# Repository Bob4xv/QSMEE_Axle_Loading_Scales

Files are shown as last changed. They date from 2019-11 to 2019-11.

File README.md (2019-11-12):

This project was created for the Queensland Society of Model and Experimental Engineers (QSMEE) 
to provide a facility to measure the load presented by a locomotive axles individually.  This
enables the builders of their scale model locomotives to equalize each axle as required on both 
5" and 7 1/4" gauge track.
A facility was added to add each axle to memory giving a total weight of the locomotive.

Hardware requirements:-
Arduino uno processor, HX711 SPI Loadcell ADC, 8 character 7 segment LED I2C display module.
The load cells are two LC4103-K100 in parallel supporting a track segment.

Software requirements:-
Arduino IDE with the following libraries installed. 
	LedControl-master from git-hub.  https://github.com/wayoda/LedControl
	HX711_ADC-master from git-hub. https://github.com/olkal/HX711_ADC & https://github.com/bogde/HX711

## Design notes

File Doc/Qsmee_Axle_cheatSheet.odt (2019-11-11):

QSMEE Axle load Scales

User Guide

POWER ON :

Push the Power switch down and hold until the display lights up with “8888” then

release. This will power the scales up for approx 30 minutes and then power it self

down.

Zero Reading:

Pressing this button down while there is no weight on the measuring part of the track

will set the tare weight to zero. Use this switch when ever the weight display does

not read 0.0 on the right hand end of the display when there is no load on the scales.

Mem +

Pressing the right hand Mem + switch down will cause the current weight displayed

on the right hand end of the display to be added to the MEMORY part of the display

on the left hand side.

Mem Clr

Pressing the right hand Mem Clr button up will reset the value in MEMORY back to

zero.

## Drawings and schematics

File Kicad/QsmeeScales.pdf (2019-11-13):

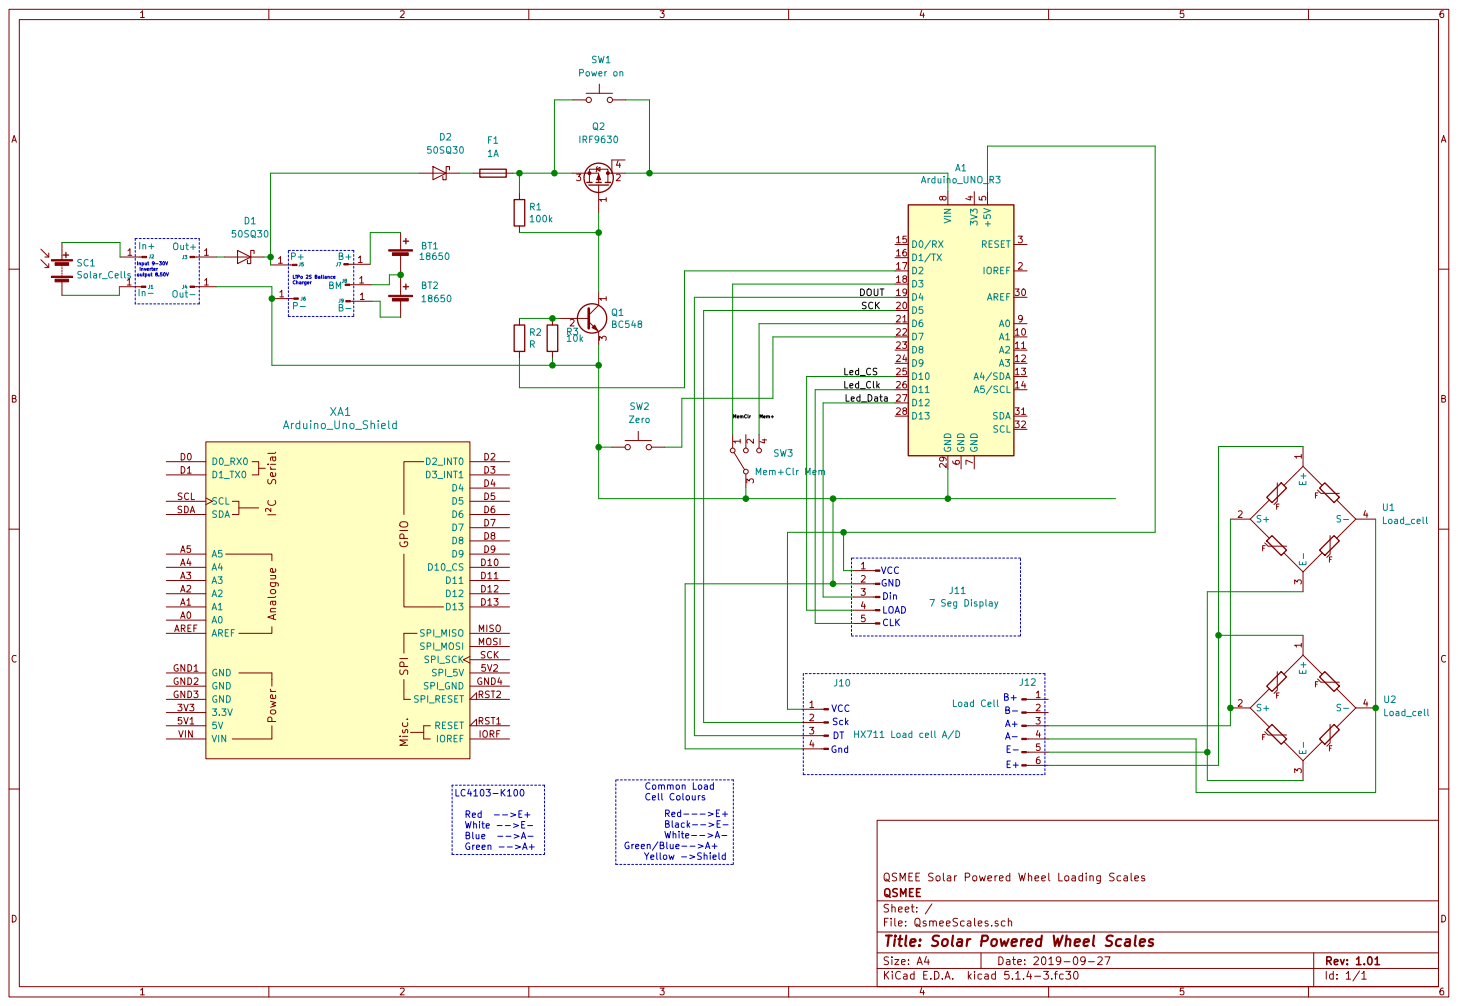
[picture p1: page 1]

QSMEE Solar Powered Wheel Loading Scales 12345

File: QsmeeScales.sch Sheet: / QSMEE

Id: 1/1 Title: Solar Powered Wheel Scales

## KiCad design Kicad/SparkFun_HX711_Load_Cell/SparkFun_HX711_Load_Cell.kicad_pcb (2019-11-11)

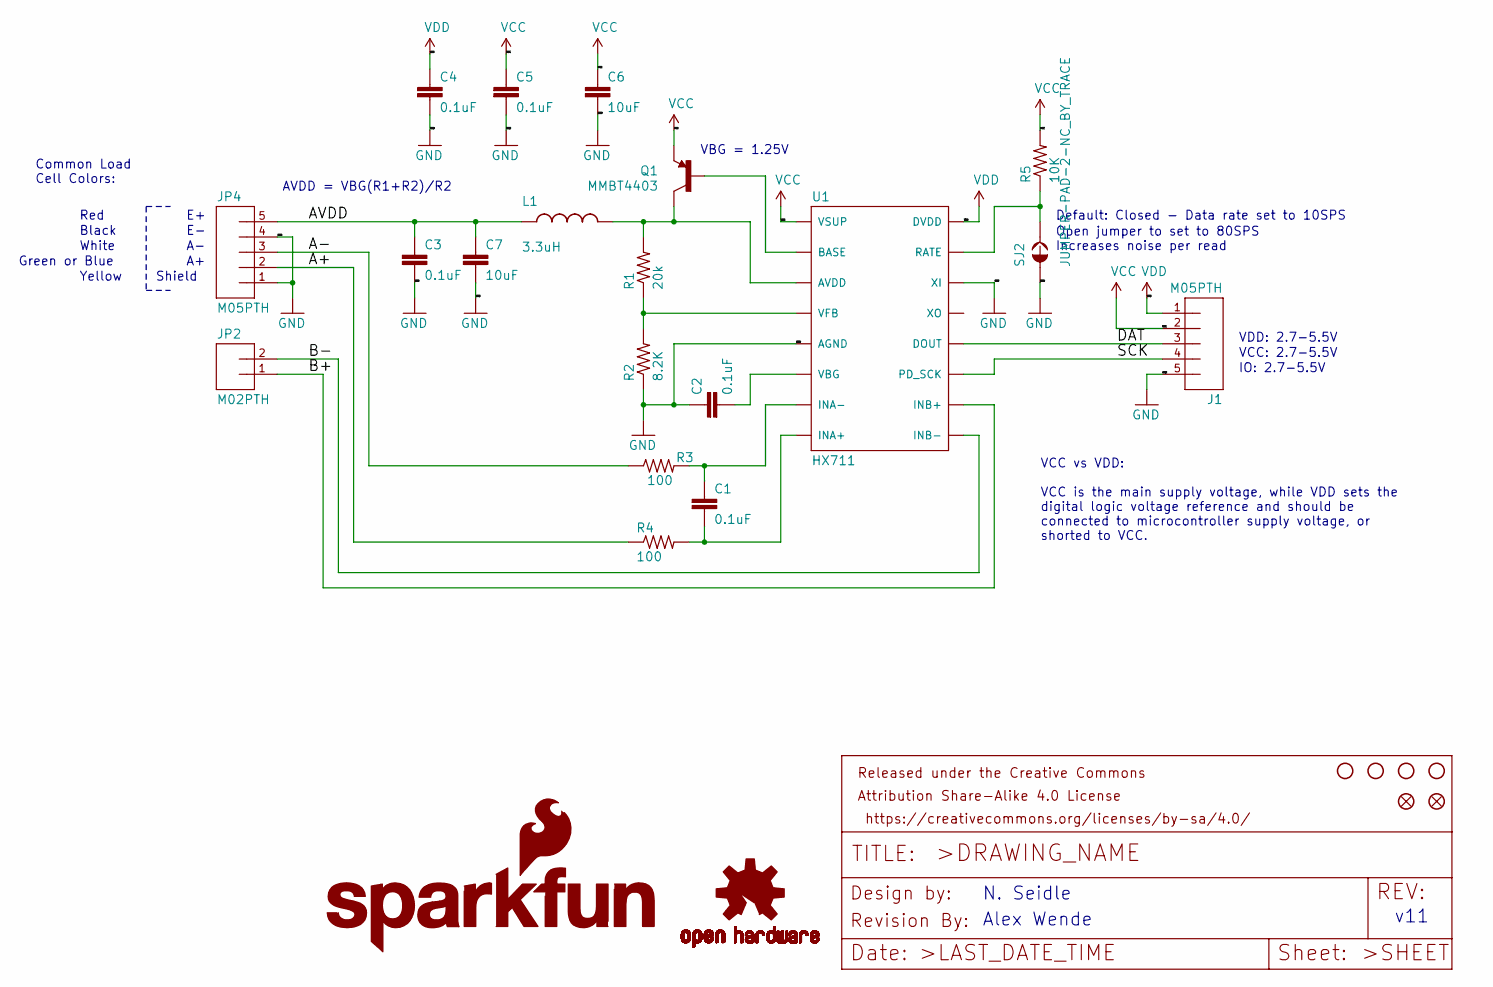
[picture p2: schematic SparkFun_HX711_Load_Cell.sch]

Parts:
C1, C2, C3, C4, C5: 0.1uF; 0603-CAP
C6, C7: 10uF; 1210
FID1, FID2: FIDUCIAL1X2; FIDUCIAL-1X2
FRAME1: FRAME-LETTER; CREATIVE_COMMONS
J1: M05PTH; 1X05
JP2: M02PTH; 1X02
JP4: M05PTH; 1X05
L1: 3.3uH; 0805
LOGO1: SFE_LOGO_NAME_FLAME.1_INCH; SFE_LOGO_NAME_FLAME_.1
Q1: MMBT4403; SOT23-3
R1: 20k; 0603-RES
R2: 8.2K; 0603-RES
R3, R4: 100; 0603-RES
R5: 10K; 0603-RES
SJ2: JUMPER-PAD-2-NC_BY_TRACE; PAD-JUMPER-2-NC_BY_TRACE_YES_SILK
STANDOFF1, STANDOFF2, STANDOFF3, STANDOFF4: STAND-OFF
U1: HX711; SO16
U7: OSHW-LOGOS; OSHW-LOGO-S
U$1: REVISION

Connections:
/A+: JP4.2, R4.1
/A-: JP4.3, R3.1
/AVDD: C3.1, C7.1, JP4.5, L1.1
/B+: JP2.1, U1.10 (INB+)
/B-: JP2.2, U1.9 (INB-)
/DAT: J1.3, U1.12 (DOUT)
/SCK: J1.4, U1.11 (PD_SCK)
GND: C2.1, C3.2, C4.2, C5.2, C6.2, C7.2, J1.5, JP4.1, JP4.4, R2.1, SJ2.1, U1.5 (AGND), U1.14 (XI)
unnamed: C1.1, R3.2, U1.7 (INA-)
unnamed: C1.2, R4.2, U1.8 (INA+)
unnamed: C2.2, U1.6 (VBG)
unnamed: L1.2, Q1.3 (C), R1.2, U1.3 (AVDD)
unnamed: Q1.1 (B), U1.2 (BASE)
unnamed: R1.1, R2.2, U1.4 (VFB)
unnamed: R5.1, SJ2.2, U1.15 (RATE)
VCC: C5.1, C6.1, J1.2, Q1.2 (E), R5.2, U1.1 (VSUP)
VDD: C4.1, J1.1, U1.16 (DVDD)

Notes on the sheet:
VCC: 2.7-5.5V
VBG = 1.25V
AVDD = VBG(R1+R2)/R2
Default: Closed - Data rate set to 10SPS
Open jumper to set to 80SPS Increases noise per read
IO: 2.7-5.5V
Shield
VDD: 2.7-5.5V
VCC vs VDD: VCC is the main supply voltage, while VDD sets the digital logic voltage reference and should be connected to microcontroller supply voltage, or shorted to VCC.
Alex Wende
N. Seidle
v11
Yellow
Common Load Cell Colors:
Green or Blue
White
Black
Red

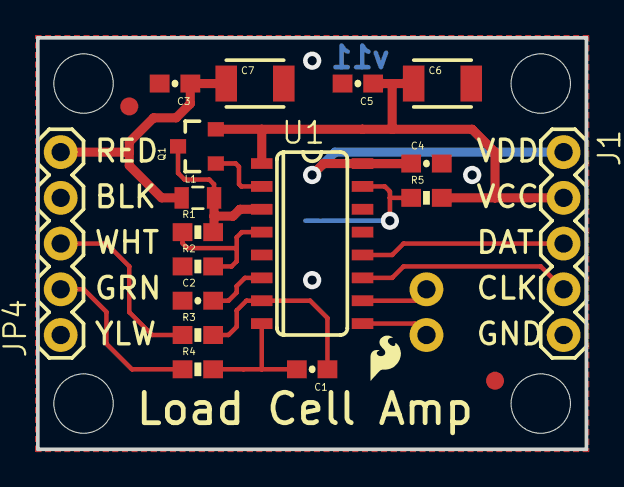
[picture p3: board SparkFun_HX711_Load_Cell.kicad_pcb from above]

Board: 2 copper layers, 30.5 x 22.9 mm, 30 parts (0 on the bottom side), 17 nets.

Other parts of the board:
LOGO3: SFE_LOGO_FLAME.1_INCH; SFE_LOGO_FLAME_.1

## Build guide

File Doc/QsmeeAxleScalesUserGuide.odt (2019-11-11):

QSMEE Axle load Scales

QSMEE axle weighing scales by Bob Campbell.

Using the HX711 ADC SPI module and I2c 7 segment display from e-bay.

Processor is Arduino Uno

Libraries used are LedControl-master from git-hub.

https://github.com/wayoda/LedControl

HX711_ADC-master from git-hub.

https://github.com/olkal/HX711_ADC & https://github.com/bogde/HX711

The load cells are two LC4103-K100 in parallel supporting a track segment.

User Guide

POWER ON :

Push the Power switch down and hold until the display lights up with “8888” then

release. This will power the scales up for approx 30 minutes and then power it self

down.

Zero Reading:

Pressing this button down while there is no weight on the measuring part of the track

will set the tare weight to zero. Use this switch when ever the weight display does

not read 0.0 on the right hand end of the display when there is no load on the scales.

Mem +

Pressing the right hand Mem + switch down will cause the current weight displayed

on the right hand end of the display to be added to the MEMORY part of the display

on the left hand side.

Mem Clr

Pressing the right hand Mem Clr button up will reset the value in MEMORY back to

zero.

Calibration

Attach a serial monitor to the usb port of the Arduino processor using a USB A type to USB B type cable. The baud rate is 38400, 8 bits no parity 1 stop bit.

When the processor starts you should see the software announce its self and display the software version number. It then continuously displays the tare weight and the load on the scales about 2 times per second. While doing this it is also waiting for keyboard input commands as shown below.

Commands are entered from the keyboard as follows:-

" Calibration Usage "

" H or h Print this page "

" l move value down by 1 "

" L move value down by 10 "

" u move value up by 1 "

" U move value up by 10 "

" r Reset Calibration factor to default"

" s or S save new Calibration factor "

By placing a known weight on the scales and using the commands above get the display to read the value of the known weight. Finally when satisfied use the “s” save command to write the new calibration factor to permanent memory.

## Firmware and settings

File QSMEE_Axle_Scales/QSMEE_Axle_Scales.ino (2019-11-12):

//-------------------------------------------------------------------------------------
// QSMEE axle weighing scales by Bob Campbell.
// Using the HX711 ADC SPI module and I2c 7 segment display from ebay.
// Processor is Arduino Uno.
// Libraries used are LedControl-master from git-hub.  https://github.com/wayoda/LedControl
//    and HX711_ADC-master from git-hub. https://github.com/olkal/HX711_ADC & https://github.com/bogde/HX711
//  The load cells are two LC4103-K100 in parallel supporting a track segment.
//-------------------------------------------------------------------------------------
/* This is an example sketch on how to find correct calibration factor for your HX711:
 - Power up the scale and open Arduino serial terminal
 - After stabilizing and tare is complete, put a known weight on the load cell
 - Observe values on serial terminal
 - Adjust the calibration factor until output value is same as your known weight:
 - Sending 'h' from the serial terminal displays usage help
 - Observe and note the value of the new calibration factor
 - Saving the calibration factor places the value into EEProm
 Bob.c
 */
#include "Arduino.h"
#include <HX711.h>  //CURRENT HX711 Lib
#include <EEPROM.h>
float VERSION = 1.00;

/*
 Now we need a LedControl to work with.
 ***** These pin numbers will may not work with your hardware *****
 pin 12 is connected to the DataIn
 pin 11 is connected to the CLK
 pin 10 is connected to LOAD
 We have only a single MAX72XX.
 */
#include "LedControl.h"

/* we always wait a bit between updates of the display */
unsigned long delaytime = 500;  // time out for display 2 per second.
unsigned long offTime = 3600;   //time out for shutdown 30 Min.
unsigned long t;
unsigned long power_timeout;

//HX711 constructor
HX711 LoadCell;

// HX711 circuit wiring
const int LOADCELL_DOUT_PIN = 4;
const int LOADCELL_SCK_PIN = 5;

// LedControl(data,clk,cs,No. of devices)
LedControl lc = LedControl(12, 11, 10, 1);

int eeaddress = 0;
int gain = 64;			// 128 or 64
unsigned char samples = 2;
float Calfactor = 696.0;
float defaultScale = 582.0;
float weight = 0;
int totalweight = 0;
bool done_add = false;
const int addMemPin = 6;
const int clrMemPin = 3;
const int powerPin = 2;
const int tarePin = 7;

void write_axle_load(int load) {
	bool digit23 = false;
	bool digit34 = false;
//          Serial.print("'"); Serial.print(weight); Serial.print("'  ");
	if (load < 0) {
		lc.setChar(0, 3, '-', false);
		unsigned int wt10 = 65536 - load;   //Change to pos number
//          Serial.print("'"); Serial.print(wt10); Serial.print("'  ");
		if (wt10 >= 100) {
			lc.setDigit(0, 2, (wt10 / 100), false);
			digit23 = true;
			wt10 = load - 100;
		} else
			lc.setRow(0, 2, 0);
		if (wt10 >= 10) {
//           Serial.print("'"); Serial.print(wt10); Serial.print("'  ");
			lc.setDigit(0, 1, (wt10 / 10), true);
			digit23 = true;
			wt10 = wt10 - 10;
		} else if (!digit34) {
			lc.setRow(0, 1, 0);
		} else
			lc.setDigit(0, 1, 0, true);
		lc.setDigit(0, 0, (wt10), false);
	}
	if (load >= 0) {

//        lc.setChar(0,4,' ',false);
		if (load >= 1000) {
			lc.setDigit(0, 3, (load / 1000), false);
			lc.setDigit(0, 2, 0, false);
			digit34 = true;
			load = load - (1000 * (load / 1000));
		} else
			lc.setRow(0, 3, 0);
		if (load >= 100) {
			lc.setDigit(0, 2, (load / 100), false);
			lc.setDigit(0, 1, 0, true);
			digit23 = true;
			load = load - (100 * (load / 100));
		} else if (!digit34) {
			lc.setRow(0, 2, 0);
		} else if (!digit23) {
			lc.setDigit(0, 2, 0, true);
		}
		if (load >= 10) {
			lc.setDigit(0, 1, (load / 10), true);
			digit23 = true;
			load = load - (10 * (load / 10));
		} else if (!digit23) {
			lc.setDigit(0, 1, 0, true);
		} else
			lc.setDigit(0, 1, 0, true);
		lc.setDigit(0, 0, load, false);
	}

}

void write_mem(int mem) {

	lc.setRow(0,7,0);	// clear all
	lc.setRow(0,6,0);
	lc.setRow(0,5,0);
	if (mem >= 0) {
		mem = mem / 10;			// remove decimal
	}
	if (mem >= 1000) {
			lc.setDigit(0, 7, (mem / 1000), false);
			lc.setDigit(0, 6, 0, false);
			lc.setDigit(0, 5, 0, false);
			mem = mem - (1000 * (mem / 1000));
	}
	if (mem >= 100) {
			lc.setDigit(0, 6, (mem / 100), false);
			lc.setDigit(0, 5, 0, false);
			lc.setDigit(0, 4, 0, false);
			mem = mem - (100 * (mem / 100));
	}
	if (mem >= 10) {
			lc.setDigit(0, 5, (mem / 10), false);
			mem = mem - (10 * (mem / 10));
	}
	lc.setDigit(0, 4, mem, false);
}

void do_tare() {
	long int tare_value = 0;
	LoadCell.tare();
	tare_value = LoadCell.get_offset();
	Serial.print("Tare Value = ");
	Serial.println(tare_value);
}

void new_tare() {
	long int tare_value = 0;
	tare_value = LoadCell.read();
//	LoadCell.set_offset(tare_value);
	Serial.print("New Tare Value = ");
	Serial.println(tare_value);
}

void do_help() {
	Serial.println("  Calibration Usage ");
	Serial.println("  H or h Print this page ");
	Serial.println("  l move value down by 1 ");
	Serial.println("  L move value down by 10 ");
	Serial.println("  u move value up by 1 ");
	Serial.println("  U move value up by 10 ");
	Serial.println("  r Reset Scalefactor to default");
	Serial.println("  s or S save new Calfactor ");
}

void do_saveScale(float newscale) {

	EEPROM.put(eeaddress, newscale);  //update non-volitle calibration
	Serial.print(" **** New Calibrate factor = ");
	Serial.println(newscale);

}

void setup() {
	pinMode(addMemPin, INPUT_PULLUP);
	pinMode(clrMemPin, INPUT_PULLUP);
	pinMode(tarePin, INPUT_PULLUP);
	pinMode(powerPin, OUTPUT);

	Serial.begin(38400);
	delay(50);
	Serial.println("QSMEE Axle Load Measurement Scales");
	delay(20);
	Serial.print("VERSION ");
	Serial.println(VERSION);

	/*
	 The MAX72XX is in power-saving mode on startup,
	 we have to do a wakeup call
	 */
	lc.shutdown(0, false);
	/* Set the brightness to a medium values */
	lc.setIntensity(0, 8);
	/* and clear the display */
	lc.clearDisplay(0);
	write_axle_load(8888);		//Show startup

	Serial.println("Wait...");
	digitalWrite(powerPin, HIGH);  			//latch power on
	power_timeout = 0;			// Start
	LoadCell.begin(LOADCELL_DOUT_PIN, LOADCELL_SCK_PIN, gain);
	delay(5000);
	LoadCell.power_up();
	LoadCell.wait_ready(20);
	do_tare();
	LoadCell.wait_ready(1);
	totalweight = 0;

	EEPROM.get(eeaddress, Calfactor);
	Serial.print("Calfactor = ");
	Serial.println(Calfactor);

	/*
	 * Has non volatile EEPROM ever been set?
	 */
	if (Calfactor < 10) {
		Calfactor = defaultScale;  //default value
		EEPROM.put(eeaddress, defaultScale);
	}
	LoadCell.set_scale(Calfactor);
	LoadCell.wait_ready(1);


	Serial.println("Startup + tare is complete");
}

void loop() {
//	int weight=0;

	//get smoothed value from data set + current calibration factor
	if (millis() > t + delaytime) {
		LoadCell.wait_ready(10);
		float f_weight = LoadCell.get_units(samples); // Kg.
		Serial.print("   Load_cell TimeCount: ");
		Serial.print(power_timeout);
		Serial.print("   Load_cell output val: ");
		Serial.println(f_weight / 10);
		t = millis();
		power_timeout = power_timeout + 1;
		if (power_timeout >= offTime) {
			digitalWrite(powerPin, LOW);
		}
		done_add = false;
		weight = int(f_weight);
		write_axle_load(weight);
	}

	while (!digitalRead(addMemPin)) {   //do only one add per keypress
		if (!done_add) {
			totalweight = totalweight + weight;
			done_add = true;
			Serial.println("**** ADD MEM ");
			write_mem(totalweight);
		}
	}
	done_add=false;
	while (!digitalRead(clrMemPin) && (totalweight != 0)) { //reset
		Serial.println("**** Clear MEM ");
		totalweight = 0;
		write_mem(totalweight);
		lc.clearDisplay(0);
	}

	//receive from serial terminal
	if (Serial.available() > 0) {
		float inc = 0;
		float newscale = 0;
		char crud[5];
		char inByte = Serial.read();
		Serial.readBytes(crud, 5);
		if (inByte == 'l')
			inc = 1.0;
		else if (inByte == 'L')
			inc = 10.0;
		else if (inByte == 'u')
			inc = -1.0;
		else if (inByte == 'U')
			inc = -10.0;
		else if (inByte == ('h'))
			do_help();
		else if (inByte == ('H'))
			do_help();
		else if (inByte == 's') {
			newscale = LoadCell.get_scale();
			do_saveScale(newscale);
		} else if (inByte == 'r') {
			newscale = defaultScale;
		} else
			do_help();
		newscale = LoadCell.get_scale() + inc;
		Serial.print("Scale = ");
		Serial.println(newscale);
		LoadCell.set_scale(newscale);
	}
	if (!digitalRead(tarePin)) {
		do_tare();
	}

}

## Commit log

2019-11-12 Update README.md fix typo QSMEE_Axle_Scales.ino
    [QSMEE_Axle_Scales.ino]
2019-11-12 Fix symlink on .ino and update README
    [QSMEE_Axle_Scales.ino]
2019-11-13 Tidy up schematic and add PDF
    [QsmeeScales.sch]

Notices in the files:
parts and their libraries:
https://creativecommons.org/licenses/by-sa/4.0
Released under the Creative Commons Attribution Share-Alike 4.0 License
